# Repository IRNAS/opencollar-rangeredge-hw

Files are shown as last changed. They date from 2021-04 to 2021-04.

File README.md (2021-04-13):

# Opencollar RhinoEdge tracker hardware
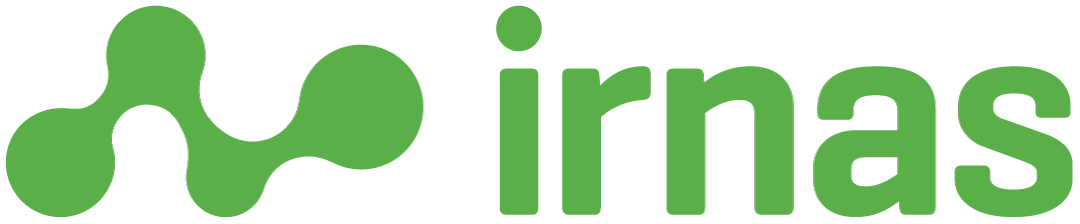
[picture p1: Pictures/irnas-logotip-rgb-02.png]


PCB specifications:
- 4 Layer PCB
- 1.6mm PCB thickness
- 0.127mm (5mil) trace to trace and trace to polygon clearance
- 0.137mm RF line thickness
- PCB dimensions 59.8mm x 95.8mm x 1.6mm

PCB view
<p align="center">
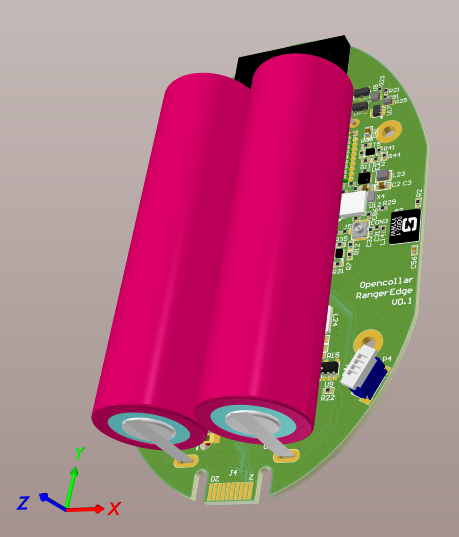
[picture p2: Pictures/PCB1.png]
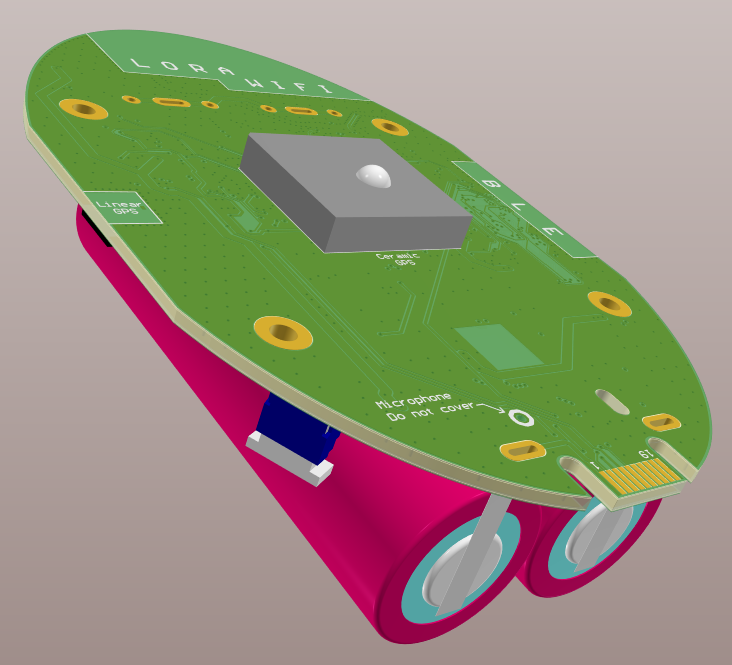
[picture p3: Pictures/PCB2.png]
					
</p>
 - Future changes:
	- 
  
Currently under development, for all information see the [schematic PDF file](https://github.com/IRNAS/opencollar-rangeredge-hw/tree/master/Documentation/RangerEdge_V0.1_SCHEMATICS).Produced board versions can be found in the [release section](https://github.com/IRNAS/opencollar-rangeredge-hw/releases) of the repository.

**Latest release: [v0.1](https://github.com/IRNAS/opencollar-rangeredge-hw/tree/master/Documentation)**

All comments and suggestions can be added to the [Issues](https://github.com/IRNAS/opencollar-rangeredge-hw/issues) section of the repo.

---

## Licensing

Pangolin tracker hardware with documentation is licensed under [CERN OHL v.1.2. license](https://www.ohwr.org/licenses/cern-ohl/license_versions/v1.2).

What this means is that you can use this hardware and documentation without paying a royalty and knowing that you'll be able to use your version forever. You are also free to make changes but if you share these changes then you have to do so on the same conditions that you enjoy.

IRNAS is name and mark of Institute IRNAS Rače. You may use these name and terms only to attribute the appropriate entity as required by the Open Licence referred to above. You may not use them in any other way and in particular you may not use them to imply endorsement or authorization of any hardware that you design, make or sell.
*

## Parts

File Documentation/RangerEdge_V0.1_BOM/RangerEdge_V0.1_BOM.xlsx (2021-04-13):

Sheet: Part List Report
 | Component list |  |  | RangerEdge
 | Source Data From: | RangerEdge.PrjPCB |  |  | Contact:
 | Project: | RangerEdge.PrjPCB
 | Variant: | None |  |  |  |  |  |  | IRNAS
 | Report Date: | 13. 04. 2021 | 08:22 |  |  |  |  |  | www.irnas.eu
 | Print Date: | 2021-04-13 | 8:22:18
# | Manufacturer Part Number | Manufacturer | Description | Footprint | Designator | Quantity | Supplier 1 | Supplier Part Number 1 | Supplier Order Qty 1 | Supplier Stock 1 | Supplier Unit Price 1 | Supplier Subtotal 1 | Supplier Currency 1
1 | LFXTAL009678 | IQD | Crystal, 32.768 kHz, SMD, 2mm x 1.2mm, 9 pF, 10 ppm, 9HT11 Series | 9HT11 | X4 | 1 | Farnell | 2819312
2 |  |  | BATERRY HOLDER 18650 | BATTERY 18650 - THT TAB | P2, P3 | 2
3 |  |  | Pin Header, Top Entry, Wire-to-Board, 1 mm, 1 Rows, 3 Contacts, Surface Mount, SR Series | BM02B-SRSS | P1 | 1 | Farnell | 1679127
4 |  |  | Pin Header, Top Entry, Wire-to-Board, 1 mm, 1 Rows, 4 Contacts, Surface Mount, SR Series | BM04B-SRSS | P4, P5 | 2 | Farnell | 1679129
5 | 04025A150JAT2A | Kyocera AVX | AVX 04025A150JAT2A Multilayer Ceramic Capacitor, 15 pF, 5%, C0G / NP0, 50 V, 0402 [1005 Metric] | CAP0402 | C56 | 1 | Farnell | 2367620
6 |  |  | CAP CER 27PF 50V C0G/NP0 0402 | CAP0402, rlc_402_smd_small | C39, C42, C43, C44, C45, C47, C48, C57, C58, C59 | 10 | Digi-Key | 490-11384-1-ND
7 | MC0402X104J160CT, CC0402JRX7R7BB104 | Multicomp, Yaego | MULTICOMP MC0402X104J160CT SMD Multilayer Ceramic Capacitor, 0402 [1005 Metric], 0.1 F, 16 V, 5%, X5R, MC Series New, CAP 100nF 16V X5R 0402, 0.1 F, 16 V, 5%, X5R, MC Series | CAP0402, rlc_402_smd_small | C1, C34, C49, C50, C52, C75, C77, C81, C84, C86, C88, C90 | 12 | Farnell | 2627419, 3369125
8 | CL10A106KP8NNNC, GRM188R60G226MEA0D | Samsung | Cap Ceramic 10uF 10V X5R 10% SMD 0603 85C Paper T/R, 22 µF, 4 V, 0603 [1608 Metric], ± 20%, X5R, GRM Series, CAP 10UF 10V X5R 0603 | CAP0603, rlc_603_smd_small | C2, C3, C51, C60, C61, C71, C74, C83 | 8 | Farnell, Digi-Key | 2456110, 1907502, 1276-1192-1-ND
9 | CGA4J1X5R1C106K125AC | TDK | 10UF, 16V, 0805 | CAP0805 | C72, C73 | 2 | Farnell | 2611943
10 | MM8130-2600 | Murata | Coaxial Connector with Switch | COAXIAL-SWF | J1, J2, J3, J5, J6, J7, J8 | 7
11 | ABS06-107-32.768KHZ-T | Abracon | 32.768KHz 4pF Max. ESR 81 Kohms | CRY2X1.2 | X1 | 1 | Farnell | 2467860
12 | ABS06-107-32.768KHZ-T | Abracon | TCXO Oscillators 32MHz 1ppm 1.7V to 3.465V | CRY2.5X2 | X2 | 1 | Mouser | 520-TXO25CSMV320BMTR
13 | NJG1801K75 | NJR | RF Switch ICs SPDT GaAs MMIC 6.0GHz 3.0V 31dBm | DFN-6-JRC | U4 | 1 | Mouser | 513-NJG1801K75
14 | NJG1804K64 | NJRC | SP3T SWITCH GAAS MMIC | DFN-8 | U2, U14 | 2 | Digi-Key | 190-NJG1804K64-TE1CT-ND
15 |  |  | TVS Diode, Unidirectional, 30 V, 48.4 V, DO-214AC (SMA), 2 Pins | DO-214AC (SMA) | D2 | 1 | Farnell | 1827605
16 | BGA725L6E6327FTSA1 | INFINEON | RF Amplifier IC, 20 dB Gain / 0.65 dB Noise, 1.55 GHz to 1.615 GHz | EPFFP6-X2 | U3, U5 | 2 | Farnell | 2480589
17 |  |  | Resettable Fuse, PPTC, 1210 (3225 Metric), MF-USHT Series, 30 VDC, 500 mA, 2.5 A, 0.1 s | FUSE 2920 | F1 | 1 | Farnell | 2776823
18 | SRN2009T-2R2M | Bourns | Power Inductor (SMD), 2.2 µH, 900 mA, Semishielded, 900 mA, SRN2009T Series, 2mm x 1.6mm x 0.95mm | IND2.3X1.7 | L22, L23 | 2 | Farnell | 2808272
19 |  |  | +FIXED IND 4.7NH 750MA 70MOHM | IND0402 | L17 | 1 | Farnell | 2285651
20 |  |  | FIXED IND 4.7NH 750MA 70MOHM | IND0402 | L18 | 1 | Digi-Key | 490-1139-1-ND
21 |  |  | ISP Smart Bluetooth Module | ISP1807-LR | U20 | 1 | Digi-Key | 1786-1019-1-ND
22 | KPTL-3216SURCK-01 | KINGBRIGHT | LED, Low Power, Red, SMD - Reverse Mount, 1206 (3216 Metric), 20 mA, 1.95 V, 630 nm | LED1206 - Reverse | D3 | 1 | Farnell | 2217903
23 | MPU-9250 | TDK InvenSense | MEMS Accelerometer, Digital, X, Y, Z, ± 2g, ± 4g, ± 8g, ± 16g, 1.62 V, 3.6 V | LGA-12 | U11 | 1 | Farnell | 2849615
24 | 1N4148W-7-F. | DIODES INC. | Bridge Rectifier Diode, Single Phase, 100 V, 500 mA, SOIC, 1 V, 4 Pins | MB1S | D4 | 1 | Farnell | 1467483
25 | SR42I010-R | Antenova | Antennas Passive GPS/GLONASS Patch Antenna | MPA-184 | A1 | 1 | Digi-Key | 931-1408-ND
26 | LM2596DSADJG | ON SEMICONDUCTOR | Li-Ion Battery, Li-Pol Voltage & Current Protector, Single Cell, 1.5 V to 8 V supply, | PWSON-6 | U8 | 1 | Farnell | 3123826
27 |  |  | LR1110 - Low Power Integrated UHF Transceiver with LoRa Modem | qfn32l_5x5mm | U1 | 1
28 | L76-M33 | Quectel | GPS Modules GNSS | Quectel-L76 | U25 | 1 | Mouser | 277-L76-M33
29 | MCWR04X1002FTL | Multicomp | 52.3 kohm, 50 V, 0402 [1005 Metric], 62.5 mW, 1%, MCWR Series, 10 kohm, 50 V, 0402 [1005 Metric], 62.5 mW, 1%, MCWR Series, 10 kohm, 50 V, 0402, 62.5 mW, 1%, | RES0402 | R15, R17, R19 | 3 | Farnell | 2073114, 2447096
30 | CRCW0402165KFKED | Vishay | RES SMD 165K OHM 1% 1/16W 0402 | RES0402 | R16 | 1 | Farnell | 2072686
31 | MCMR06X4701FTL | MULTICOMP | 4.7 kohm, MCWR Series, 50 V | RES0402, rlc_402_smd_small | R7, R9, R12, R13, R32, R34 | 6 | Farnell | 2447187
32 | MCWR04X1003FTL | Multicomp | MULTICOMP MCWR04X1003FTL RES, THICK FILM, 100KOHM, 1%, 0.0625W, 100KOHM, 1%, 0.0625W | RES0402, rlc_402_smd_small | R4, R29, R37, R38, R41, R42, R48, R49 | 8 | Farnell | 2447094
33 | MCMR04X000PTL | Multicomp | RESISTOR, 0402, 0R, ANTI SULFURATION | RES0402, rlc_402_smd_small | R2, R22, R31, R35, R40, R44, R46, R47 | 8 | Farnell | 2072513
34 | GRT155R71H471KE01D | Murata |  | rlc_402_smd_small | C35 | 1 | Farnell | 2672128
35 | MCMR04X3300FTL | Multicomp | 330 ohm, 62.5 mW, 1%, 50 V, 0402 [1005 Metric] | rlc_402_smd_small | R21 | 1 | Farnell | 2692084
36 |  |  | CAP CER 0.5PF 50V C0G/NP0 0402 | rlc_402_smd_small | C24, C26 | 2 | Digi-Key | 490-6264-1-ND
37 |  |  | CAP CER 0.7PF 50V C0G/NP0 0402 | rlc_402_smd_small | C30 | 1 | Digi-Key | 490-6267-1-ND
38 |  |  | CAP CER 1nF 50V C0G/NP0 0402 | rlc_402_smd_small | C41, C46 | 2 | Farnell | 2470415
39 |  |  | CAP CER 1.3PF 50V C0G/NP0 0402 | rlc_402_smd_small | C27 | 1 | Digi-Key | 490-8190-1-ND
40 | [NoParam], GRM1555C1H1R5BA01D | [NoParam], Murata | CAP CER 1.5PF 50V C0G/NP0 0402, CAP 1.5PF 50V C0G/NP0 0402 | rlc_402_smd_small | C17, C19, C23, C32 | 4 | Digi-Key | 490-6212-1-ND
41 |  |  | CAP CER 1.6PF 50V C0G/NP0 0402 | rlc_402_smd_small | C28 | 1 | Digi-Key | 490-6214-1-ND
42 |  |  | CAP CER 1.8PF 50V C0G/NP0 0402 | rlc_402_smd_small | C12 | 1 | Digi-Key | 490-6215-1-ND
43 |  |  | CAP CER 2.2nF 50V C0G/NP0 0402 | rlc_402_smd_small | C5 | 1 | Digi-Key | 490-1305-1-ND
44 |  |  | CAP CER 3.0PF 50V C0G/NP0 0402 | rlc_402_smd_small | C13 | 1 | Digi-Key | 490-7756-1-ND
45 |  |  | CAP CER 6.8PF 50V C0G/NP0 0402 | rlc_402_smd_small | C9, C14 | 2 | Digi-Key | 490-5949-1-ND
46 |  |  | CAP CER 12PF 50V C0G/NP0 0402 | rlc_402_smd_small | C25 | 1 | Digi-Key | 490-5924-1-ND
47 |  |  | CAP CER 33PF 50V C0G/NP0 0402 | rlc_402_smd_small | C29 | 1 | Digi-Key | 490-5936-1-ND
48 | C1005C0G1H470G050BA | TDK | CAP CER 47PF 50V 2% C0G 0402 | rlc_402_smd_small | C91 | 1 | Farnell | 2525003
49 |  |  | CAP CER 47PF 50V C0G/NP0 0402 | rlc_402_smd_small | C6, C7, C10, C15, C21 | 5 | Digi-Key | 490-5942-1-ND
50 | GRM155R71C103KA01D | Murata | CAP CER 10000PF 16V X7R 0402 | rlc_402_smd_small | C87 | 1 | Farnell | 2407354
51 |  |  | CAP CER ???F ??V 0402 | rlc_402_smd_small | C11, C16, C20, C53 | 4 | Digi-Key | 490-8190-1-ND
52 | MC0402N120J500CT | MULTICOMP | Ceramic Capacitor, 12 pF, 50 V, 0402 | rlc_402_smd_small | C36, C37 | 2 | Farnell | 1758943
53 |  |  | Ferrite Bead, 0402 [1005 Metric], 1 kohm, 200 mA, BLM15AG_SN Series, 1 ohm, ± 25% | rlc_402_smd_small | L2 | 1 | Farnell | 1515759
54 |  |  | FIXED IND 2.7NH 850MA 50 MOHM | rlc_402_smd_small | L7 | 1 | Digi-Key | 490-6800-1-ND
55 |  |  | FIXED IND 3.6NH 900MA 40 MOHM | rlc_402_smd_small | L15, L20 | 2 | Digi-Key | 490-6811-1-ND
56 |  |  | FIXED IND 6.8NH 700MA 90 MOHM | rlc_402_smd_small | L8 | 1 | Digi-Key | 490-1142-1-ND
57 |  |  | FIXED IND 7.5NH 570MA 130 MOHM | rlc_402_smd_small | L16, L21 | 2 | Digi-Key | 490-6846-2-ND
58 |  |  | FIXED IND 8.2NH 540MA 140 MOHM | rlc_402_smd_small | L6 | 1 | Digi-Key | 490-1144-1-ND
59 |  |  | FIXED IND 9.5NH 540MA 140 MOHM | rlc_402_smd_small | L11, L13 | 2 | Digi-Key | 490-8445-1-ND
60 |  |  | FIXED IND 22NH 310MA 300 MOHM | rlc_402_smd_small | L9 | 1 | Digi-Key | 490-6788-1-ND
61 |  |  | FIXED IND 33NH 260MA 630 MOHM | rlc_402_smd_small | L12 | 1 | Digi-Key | 490-1152-1-ND
62 |  |  | FIXED IND 47NH 210MA 1.08 OHM | rlc_402_smd_small | L3, L4, L10 | 3 | Digi-Key | 490-1154-1-ND
63 | LQG15WH18NJ02D | MURATA | IND 18NH 260MA 0.8 OHM 0402 | rlc_402_smd_small | L14 | 1 | Farnell | 3263541
64 | GRM1555C1H100FA01D | Murata | Multilayer Ceramic Capacitors MLCC - SMD/SMT 0402 10pF 50volts C0G 1% | rlc_402_smd_small | C33 | 1 | Farnell | 2611888
65 | MCMR04X000PTL | Multicomp | RESISTOR, 0402, 768k, ANTI SULFURATION | rlc_402_smd_small | R6, R11 | 2 | Farnell | 2670555
66 |  | Multicomp | SMD Chip Resistor, 0402 [1005 Metric], 220 ohm, CRCW e3 Series, 50 V, Thick Film, 63 mW | rlc_402_smd_small | R1, R36 | 2 | Farnell | 2140704
67 |  | Multicomp | SMD Chip Resistor, 0402 [1005 Metric], 390 ohm, MCWR Series, 50 V, Thick Film, 62.5 mW | rlc_402_smd_small | R39 | 1 | Farnell | 2447165
68 | CL05A474KP5NNNC | SAMSUNG ELECTRO-MECHANICS | SMD Multilayer Ceramic Capacitor, 0.47 µF, 10 V, 0402 [1005 Metric], ± 10%, X5R, CL Series | rlc_402_smd_small | C4 | 1 | Farnell | 3013336
69 |  |  | CAP CER 1PF 50V C0G/NP0 0402 | rlc_402_smd_small, CAP0402 | C22, C40 | 2 | Digi-Key | 490-6206-1-ND
70 | GRM155R61A105ME15D | Murata | CAP CER 1UF 10V 20% X5R 0402 | rlc_402_smd_small, CAP0402 | C38, C55, C76, C80, C82, C85, C93, C94 | 8 | Farnell | 2426953, 1740588
71 | [NoParam], GRM1555C1H1R2BA01D | [NoParam], Murata | CAP CER 1.2PF 50V C0G/NP0 0402, CAP 1.2PF 50V C0G/NP0 0402 | rlc_402_smd_small, CAP0402 | C8, C18, C31, C54 | 4 | Digi-Key | 490-6209-1-ND
72 |  |  | FIXED IND 3.3NH 2A 30 MOHM SMD | rlc_402_smd_small, IND0402 | L5, L19 | 2 | Digi-Key | 490-7642-1-ND
73 | MCWR04X2001FTL | Multicomp | 2.2 kohm, 62.5 mW, 1%, 50 V, 2 kohm, 62.5 mW, 1%, 50 V | rlc_402_smd_small, RES0402 | R23, R24 | 2 | Farnell | 2447148, 2447147
74 | MC0063W060311M | MULTICOMP | MCMR04X1004FTL RES, 1M, 1%, 0.0625W, 0402, THICK FILM | rlc_402_smd_small, RES0402 | R5, R10, R14, R20, R26, R28 | 6 | Farnell | 9330410
75 | MCMR04X1000FTL | Multicomp | MULTICOMP MCMR04X1000FTL SMD Chip Resistor, Ceramic, MCMR Series, 100 ohm, 50 V, 0402 [1005 Metric], 62.5 mW, 1%, 100 ohm, 50 V, 0402 [1005 Metric], 62.5 mW, 1% | rlc_402_smd_small, RES0402 | R3, R8, R18, R27, R45 | 5 | Farnell | 2072515
76 | CR0603-J/-000ELF | BOURNS | BOURNS - CR0603-J/-000ELF - RES, THICK FILM, 0R, 5%, 0.1W, 0603 | rlc_603_smd_small | R25 | 1 | Farnell | 2008343
77 | MLZ2012M150WT000 | TDK | Fixed Inductors 15 UH 20% | rlc_805_smd_small | L1 | 1 | Mouser | 810-MLZ2012M150WT000
78 | TPS22919DCKR | TI | Power Switch/Driver 1:1 N-Channel 1.5A SC-70-6 | SC70-6 | U13, U15, U17, U18 | 4 | Digi-Key | 296-TPS22919DCKRCT-ND
79 | MAX-M8Q-0 | u-blox | ZOE-M8 RF Receiver BeiDou, Galileo, GLONASS, GNSS, GPS -160dBm | S-LGA51 | U12 | 1 | Digi-Key | 672-1063-1-ND
80 |  |  | TVS DIODE 24V 7V SLP0603P2X3F | SLP0603P2X3F | D6 | 1
81 | 1N4148W-7-F. | DIODES INC. | TVS Diode, ESD9R Series, Unidirectional, 3.3 V, 7.8 V | SOD-923 | D1 | 1 | Farnell | 1776392
82 | EN25QH32B-104HIP2C | ESMT | 32 Megabit Serial Flash Memory with 4Kbyte Uniform Sector | SOIC-8 REFLOW | U19 | 1
83 | MPU-9250 | TDK InvenSense | Board Mount Hall Effect/Magnetic Sensors LP HALL 32FBDBZR | SOT23-3AL | U10 | 1 | Mouser | 595-DRV5032FBDBZR
84 | DMG2302UK-7 |  | MOSFET Transistor, N Channel, 2.8 A, 20 V, 0.061 ohm, 4.5 V, 600 mV | SOT23-3AL | T2 | 1 | Farnell | 3127315
85 | SI2374DS-T1-GE3 |  | MOSFET Transistor, N Channel, 5.9 A, 20 V, 0.025 ohm, 4.5 V, 1 V | SOT23-3AL | T3, T4 | 2 | Farnell | 2646371
86 | BD70522GUL | ROHM | Battery Charger for 1 Cell of Li-Ion, Li-Pol battery, 6V input, 4.2V / 500mA charge | SOT23-5 | U9 | 1 | Farnell | 1627187
87 | NTZD3154NT1G |  | Dual MOSFET, Dual N Channel, 540 mA, 20 V, 0.4 ohm, 4.5 V, 1 V | SOT-563 | T1, T5 | 2 | Farnell | 2533209
88 | SR4L049-L | Antenova | Antennas Inversa Left LTE Antenna | SR4L049-L | A3 | 1 | Mouser | 237-SR4L049-L
89 | DR125-330-R | COILTRONICS | Power Inductor (SMD), 22 µH, 1.1 A, Semishielded, 1.1 A, SRN5020TA Series, 5mm x 5mm x 1.8mm | SRN5020TA | L24 | 1 | Mouser | 652-SRN5020TA-220M
90 | SZP-C-0G02 | SYNZEN | GNSS: GPS, GLONASS, GALILEO, Beidou: 1.559 – 1.610 GHz | SZP-C-0G02-1 | A2 | 1
91 | BD70522GUL | ROHM | DC-DC Synchronous Buck Regulator, Adjustable, 4.4V to 30V In, 2V to 24V/1A Out, 500kHz | TDFN-8 | U7 | 1 | Farnell | 2857600
92 |  |  | TEST POINT ROUND SMD | TestPoint:1.2x1.2mm | TP3, TP4, TP5 | 3
93 | BD70522GUL | ROHM | Switching Voltage Regulators Tiny 300nA nanoPower Buck converters in uDFN and WLP pacakges | uDFN-6 | U6, U22 | 2 | Mouser | 700-MAX38640AELT+T
94 | U.FL-R-SMT-1(10) | Hirose | RF / Coaxial Connector, U.FL Coaxial, Straight Jack, Surface Mount Vertical, 50 ohm, Brass | ufl connector smd | CON1, CON2, CON3, CON4 | 4 | Farnell | 1688077
95 | VM1010 | Vesper | MICROPHONE MEMS DIGITAL PDM OMNI | VM1010 | U16 | 1
 |  |  |  |  |  | 209 |  |  | 0 |  |  | 0
Approved |  |  |  | Notes
 |  |  |  | pcs: |  | 20 |  | Total |  | 0 |  | <none>
 |  |  |  |  |  |  |  | Price for 1pcs |  | 0.00 |  | <none>

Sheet: Project Information
Project Full Path | D:\Synology Drive\IRNAS-Projects\SmartParks\SmartParks - RangerTracker\RangerEdge.PrjPCB
Project Filename | RangerEdge.PrjPCB
Variant Name | None
Data-Source Filename | RangerEdge.PrjPCB
Data-Source Full Path | D:\Synology Drive\IRNAS-Projects\SmartParks\SmartParks - RangerTracker\RangerEdge.PrjPCB
Title | BOM for Project [RangerEdge.PrjPCB] (No PCB Document Selected)
Total Quantity | 209
Report Time | 08:22
Report Date | 13. 04. 2021
Report Date & Tine | 13. 04. 2021 08:22
Output Name | BOM
Output Type | BOM_PartType
Output Generator Name | BOM
Output Generator Description | Bill of Materials

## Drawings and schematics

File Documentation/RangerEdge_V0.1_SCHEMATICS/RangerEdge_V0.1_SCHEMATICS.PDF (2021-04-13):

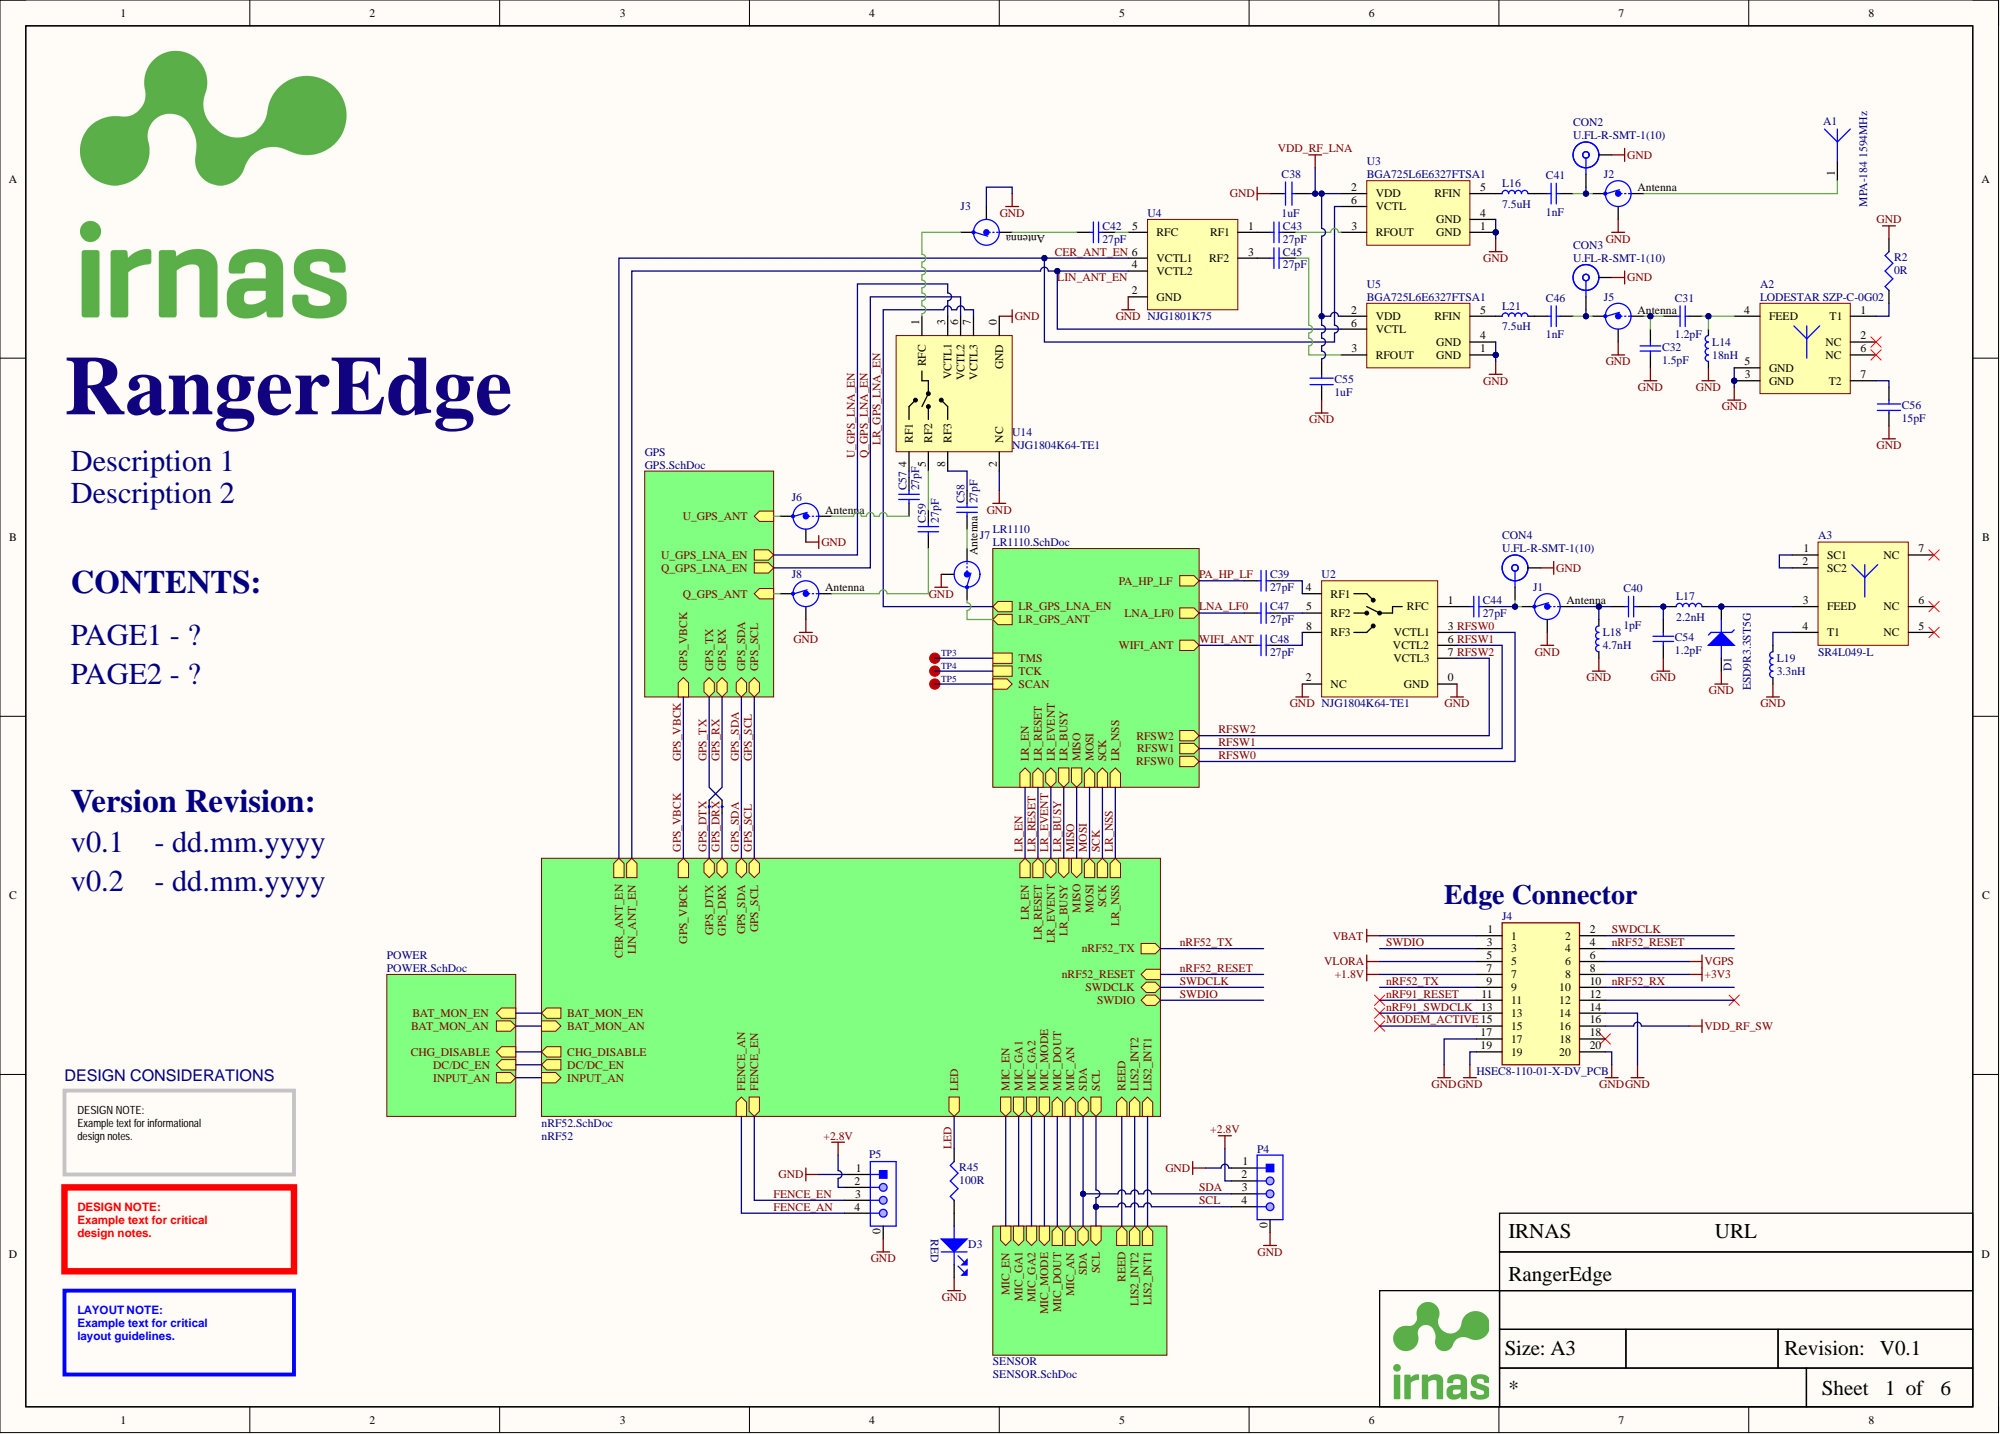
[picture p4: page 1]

VCTL2 4 | 27pF

GND 2

LR_GPS_LNA_EN LR_GPS_ANT SCAN | PA_HP_LF LNA_LF0 WIFI_ANT RFSW0 LR_NSS RFSW2 RFSW1

WIFI_ANT | C48 | | | VCTL2 | 6 VCTL1 3 RFSW1

27pF | VCTL3 | 7 RFSW2

RFSW2 | NC 2

DESIGN NOTE:
Example text for informational
design notes.

Example text for critical

LAYOUT NOTE:
layout guidelines.

Size: A3 | | Revision: V0.1

Sheet of

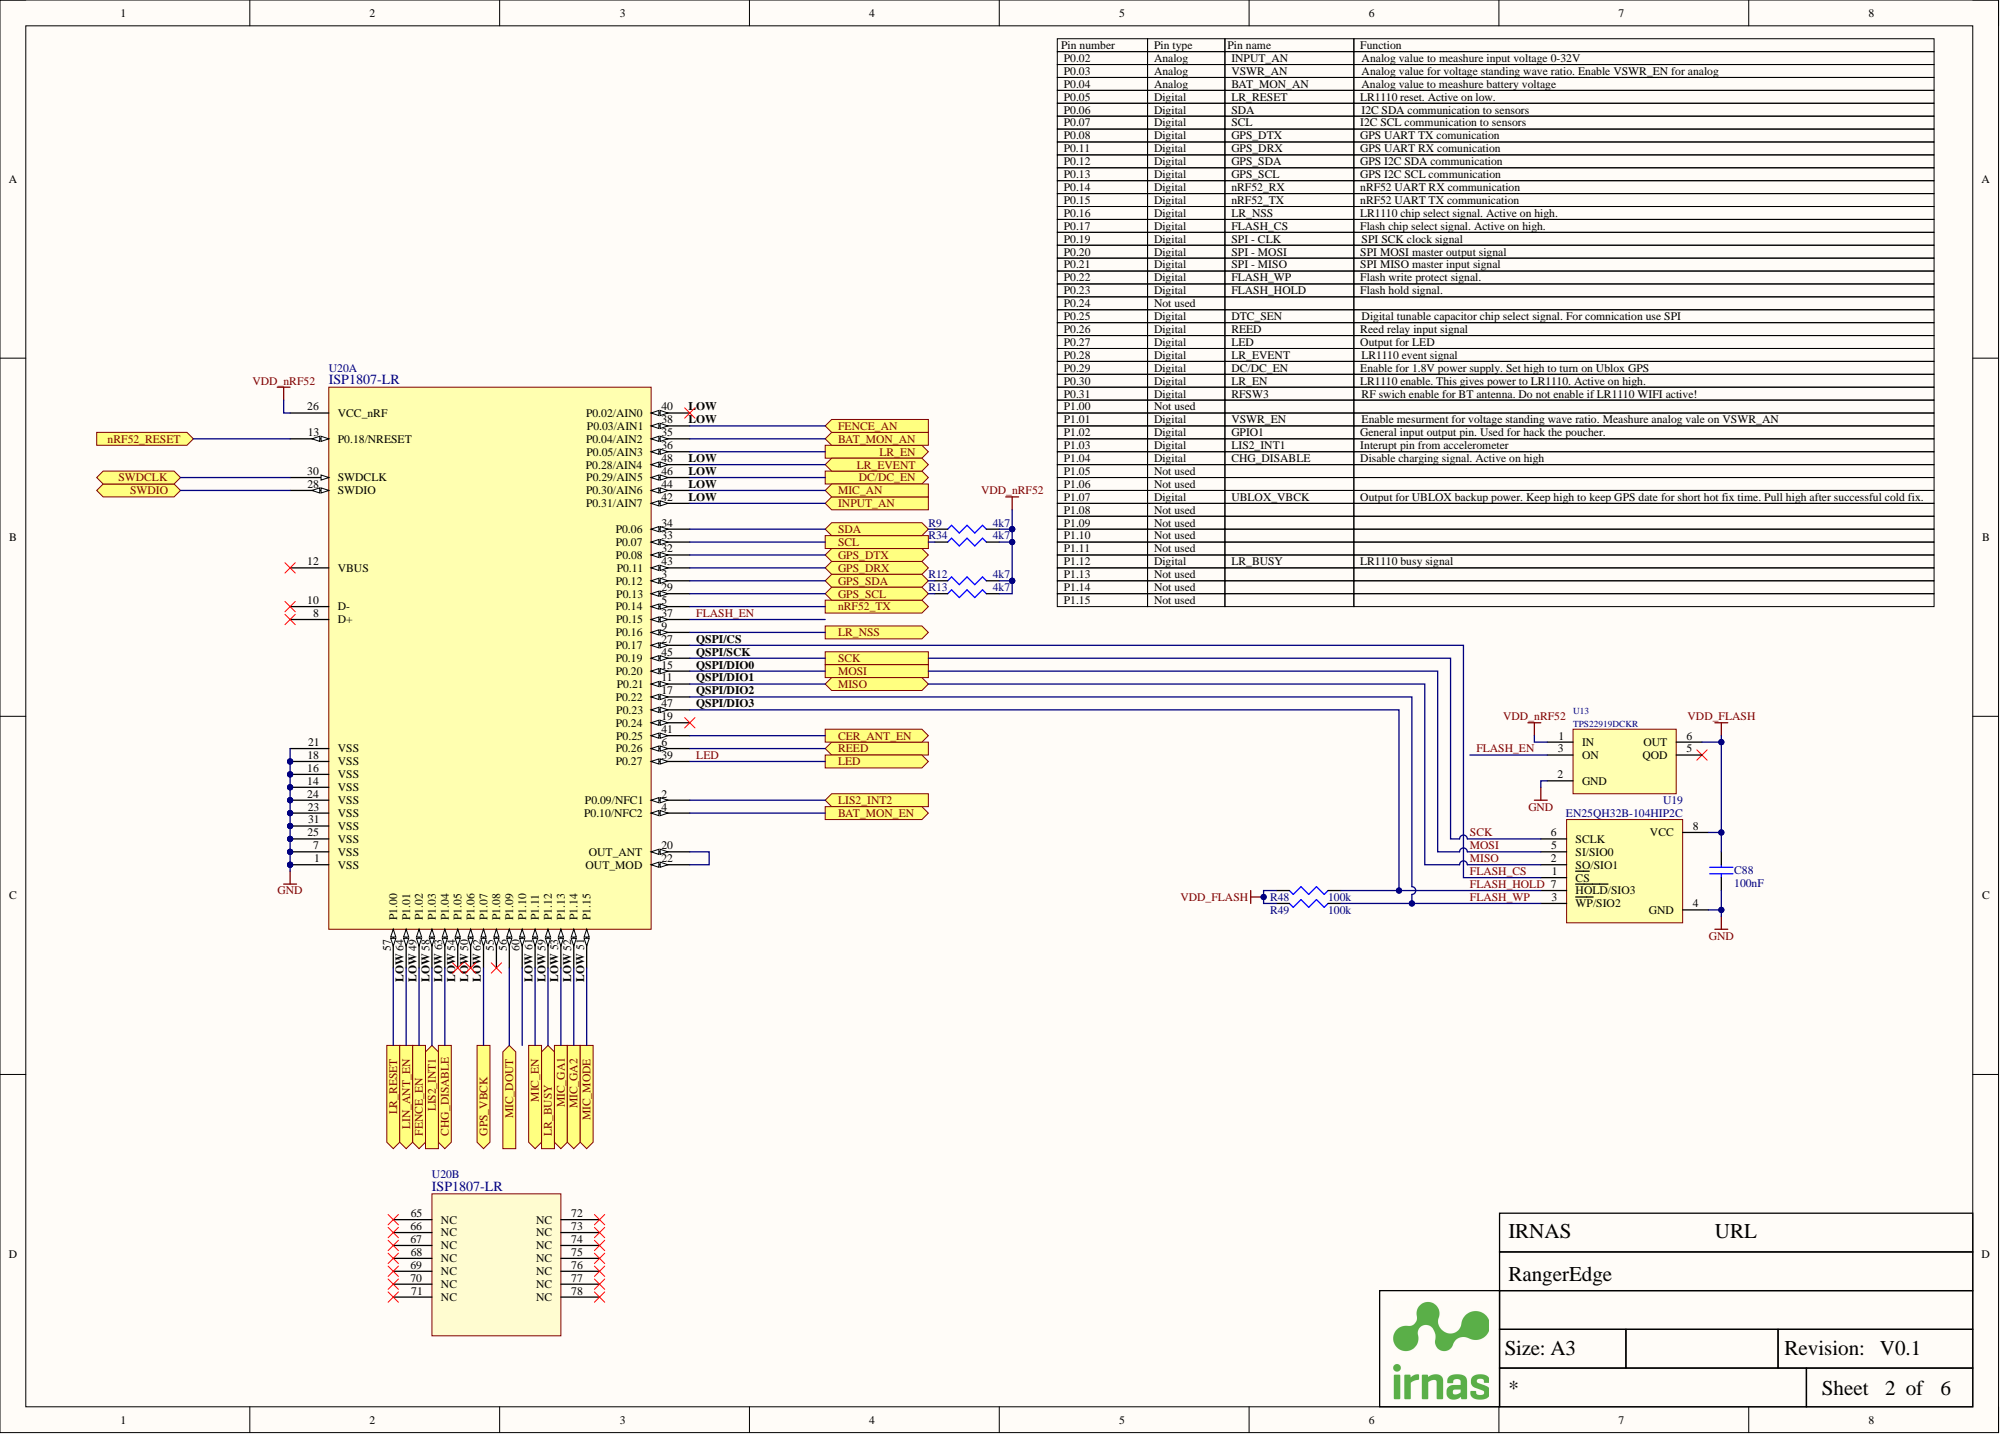
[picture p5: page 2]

Pin number | Pin type | Pin name | Function
P0.02 | Analog | INPUT_AN | Analog value to meashure input voltage 0-32V
P0.03 | Analog | VSWR_AN | Analog value for voltage standing wave ratio. Enable VSWR_EN for analog
P0.04 | Analog | BAT_MON_AN | Analog value to meashure battery voltage
P0.05 | Digital | | LR1 110 reset. Active on low .
P0.06 | Digital | SDA | I2C SDA communication to sensors

P0.07 | Digital | LR_RESET GPS_DTX GPS_DRX GPS_SDA GPS_SCL SCL | I2C SCL communication to sensors

P0.08 | Digital | | GPS UAR T TX comunication
P0.1 1 | Digital | | GPS UAR T RX comunication
P0.12 | Digital | | GPS I2C SDA communication
P0.13 | Digital
P0.14 | Digital | nRF52_RX | nRF52 UAR T RX communication

P0.15 | Digital | nRF52_TX | SPI MOSI master output signal GPS I2C SCL communication nRF52 UAR T TX communication

P0.16 | Digital | LR_NSS | LR1 110 chip select signal. Active on high.
P0.17 | Digital | FLASH_CS
P0.19 | Digital | SPI - CLK | SPI SCK clock signal
P0.20 | Digital | SPI - MOSI
P0.21 | Digital | SPI - MISO | SPI MISO master input signal
P0.22 | Digital | FLASH_WP | Flash write protect signal.

P0.23 | Digital | FLASH_HOLD | Flash chip select signal. Active on high. General input output pin. Used for hack the poucher Flash hold signal.

P0.24 | Not used
P0.25 | Digital | DTC_SEN | Digital tunable capacitor chip select signal. For comnication use SPI
P0.26 | Digital | REED | Reed relay input signal
P0.27 | Digital | LED | Output for LED
P0.28 | Digital | LR_EVENT | LR1 110 event signal
P0.29 | Digital | DC/DC_EN | Enable for 1.8V power supply. Set high to turn on Ublox GPS
P0.30 | Digital | LR_EN | LR1 110 enable. This gives power to LR1 110. Active on high.

RF swich enable for BT antenna. Do not enable if LR1

Enable mesurment for voltage standing wave ratio. Meashure analog vale on VSWR_AN

P1.02 | Digital | | .
P1.03 | Digital | LIS2_INT1 | Interupt pin from accelerometer

Disable charging signal. Active on high

P1.07 | Digital | UBLOX_VBCK | Output for UBLOX backup power. Keep high to keep GPS date for short hot fix time. Pull high after successful cold fix.
P1.08 | Not used
P1.09 | Not used
P1.10 | Not used
P1.1 1 | Not used
P1.12 | Digital | LR_BUSY | LR1 110 busy signal

QSPI/DIO0

QSPI/DIO3

VSS 18 | | LED
VSS 16 | 2

FLASH_CS
FLASH_HOLD | 7

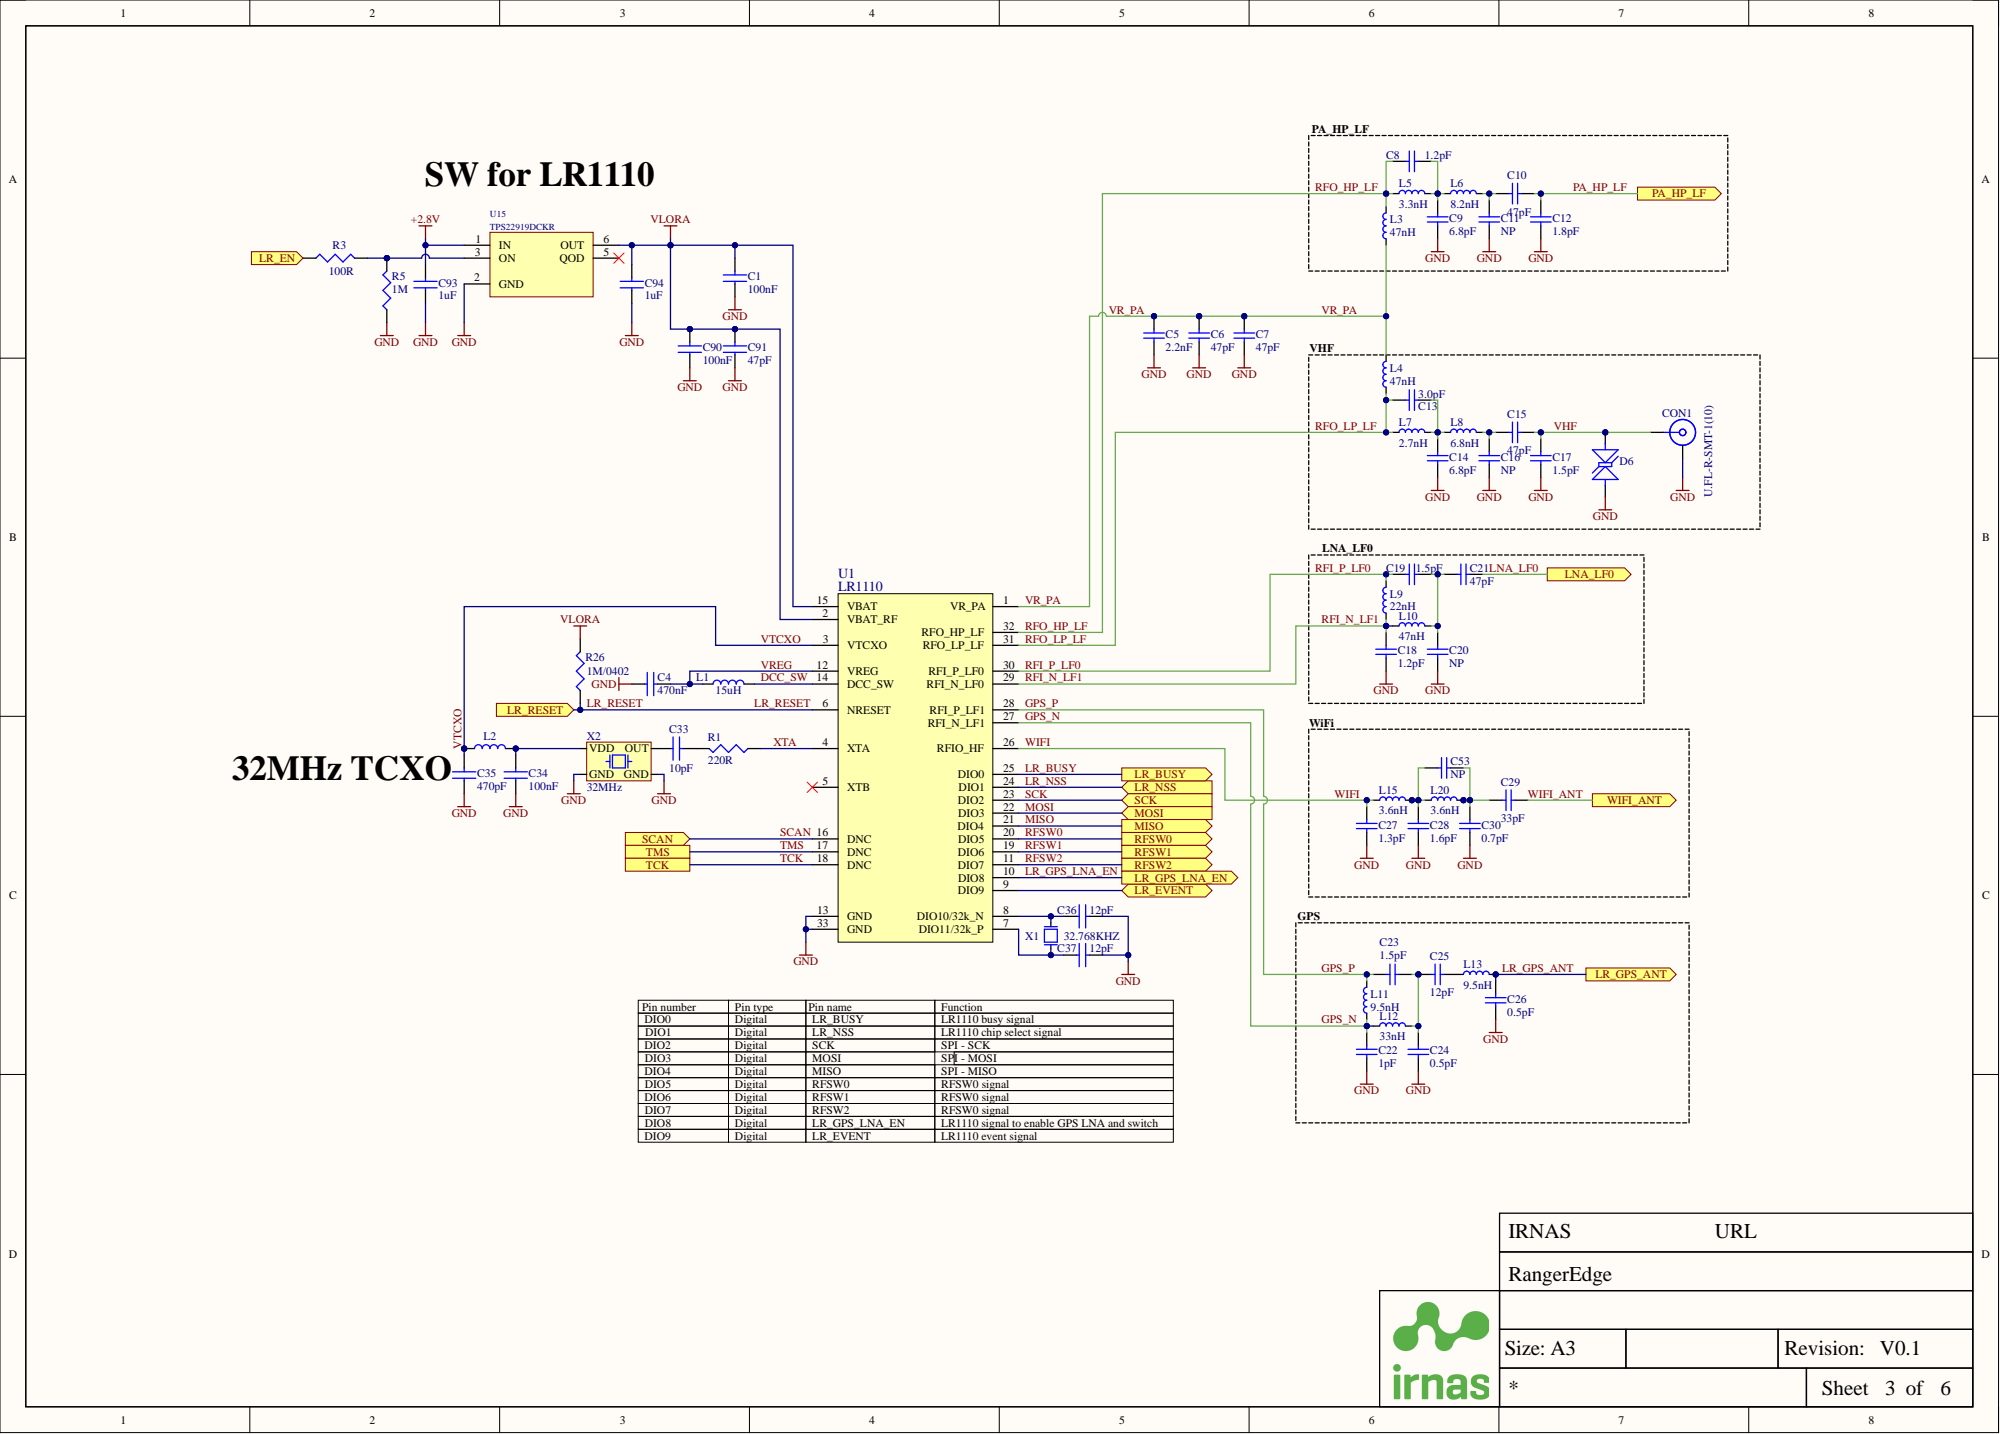
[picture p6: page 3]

LNA_LF0 RFI_P_LF0

VR_P A | RFI_N_LF1

Pin number | Pin type | Pin name | Function
DIO0 | Digital | LR_BUSY | LR1 110 busy signal
DIO1 | Digital | LR_NSS | LR1 110 chip select signal
DIO2 | Digital | SCK | SPI - SCK
DIO3 | Digital | MOSI | SPI - MOSI
DIO4 | Digital | MISO | SPI - MISO
DIO5 | Digital | RFSW0 | RFSW0 signal
DIO6 | Digital | RFSW1 | RFSW0 signal
DIO7 | Digital | RFSW2 | RFSW0 signal
DIO8 | Digital | LR_GPS_LNA_EN | LR1 110 signal to enable GPS LNA and switch
DIO9 | Digital | LR_EVENT | LR1 110 event signal

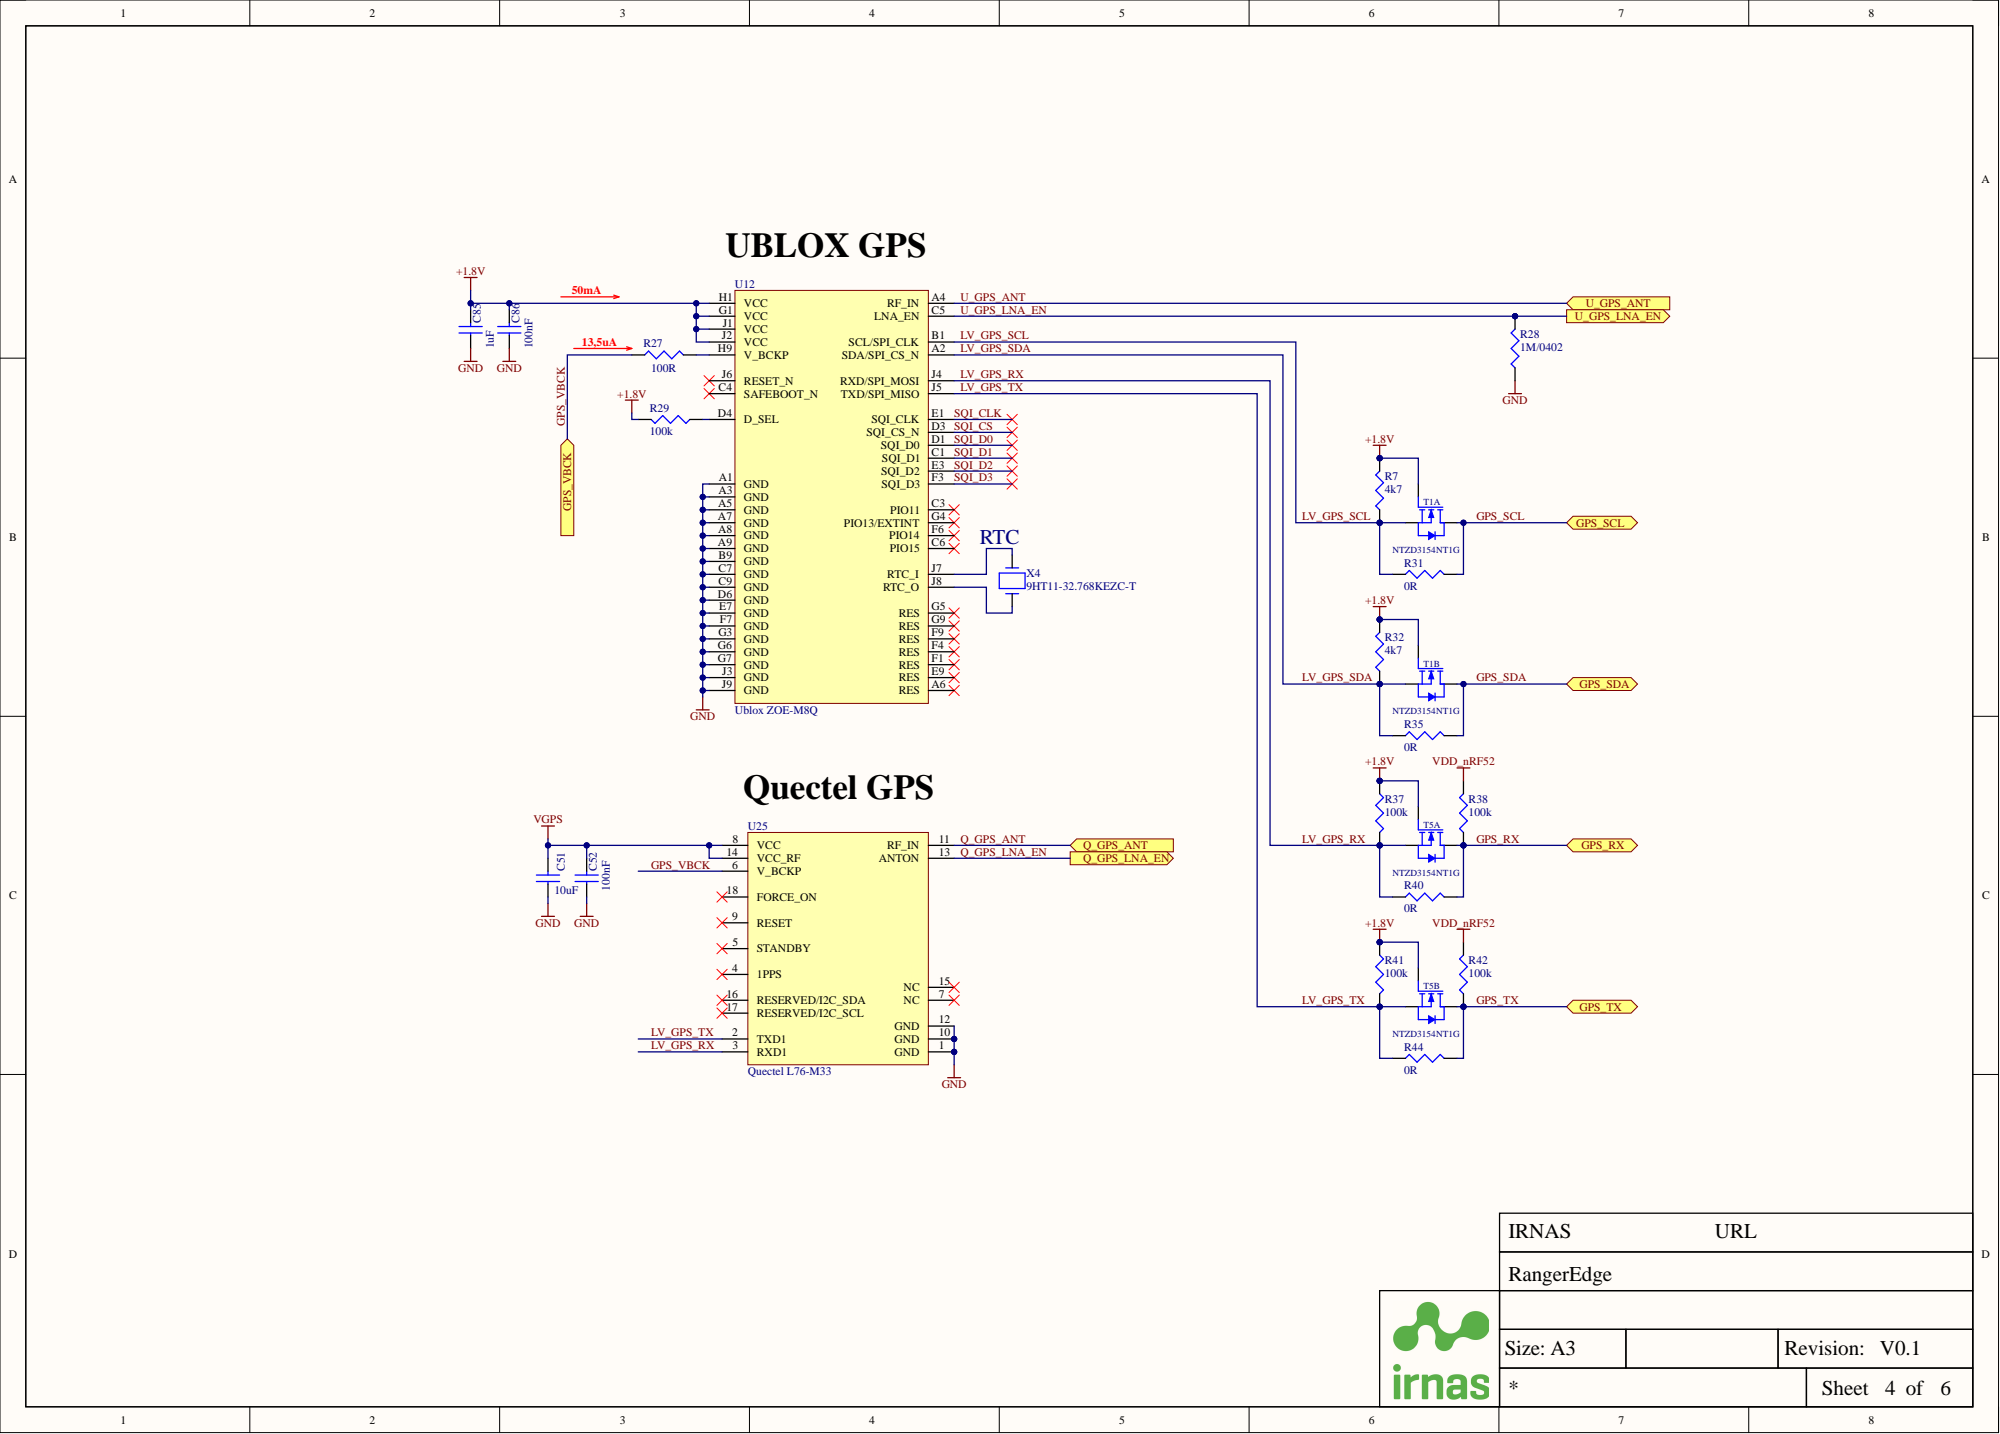
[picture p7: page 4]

LV_GPS_TX

SQI_CLK

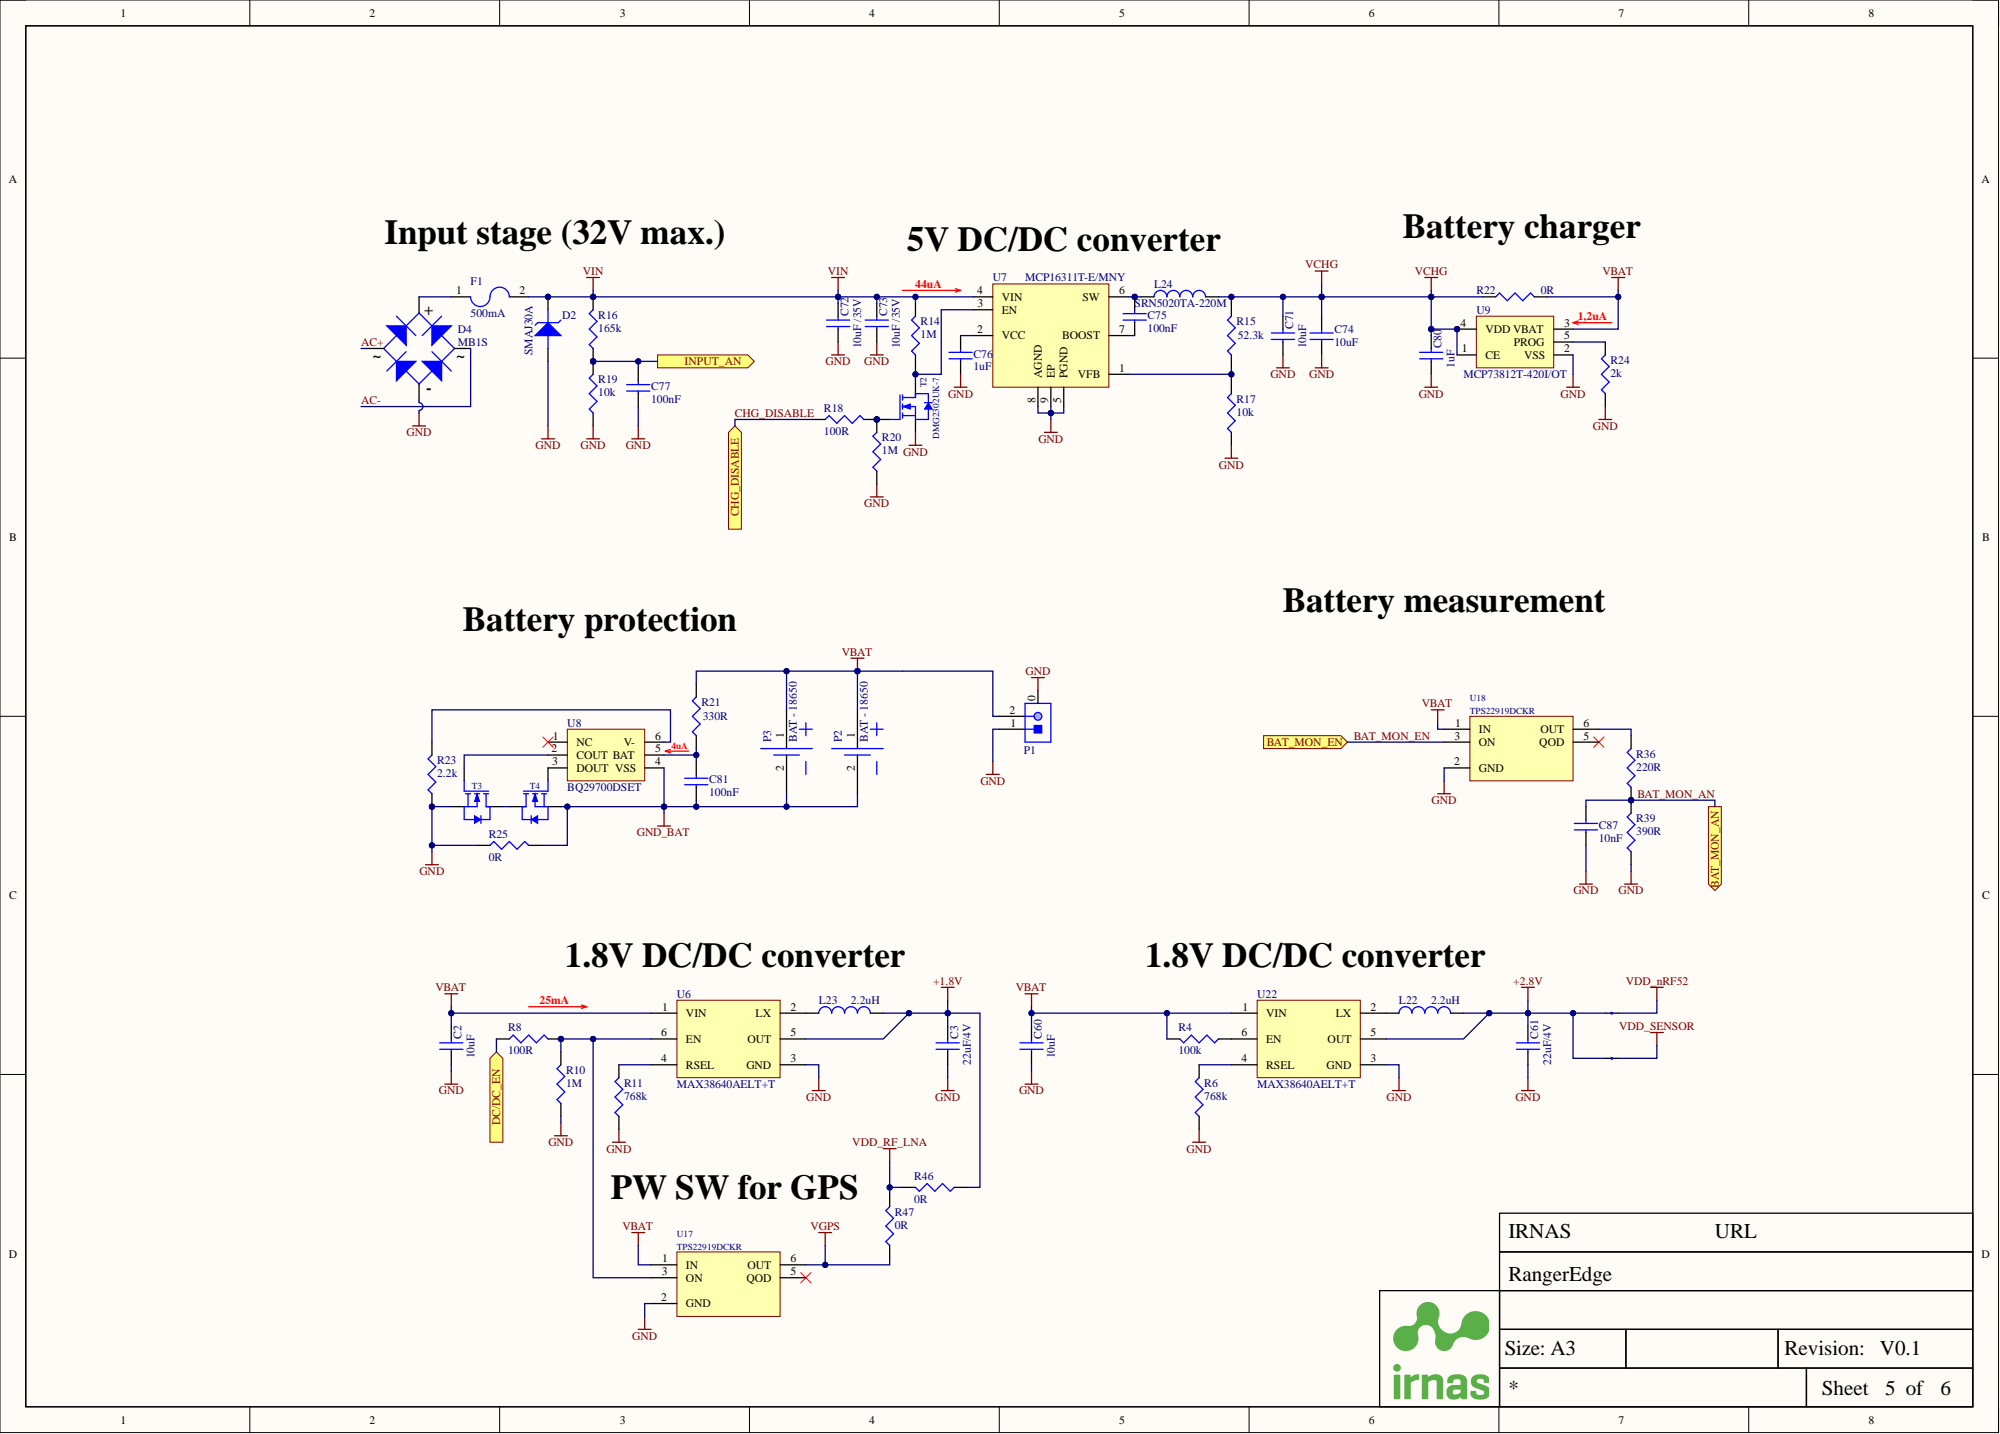
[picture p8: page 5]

DOUT 3 VSS COUT 2 | 4 BAT 5 V-6

GND
PW SW for GPS

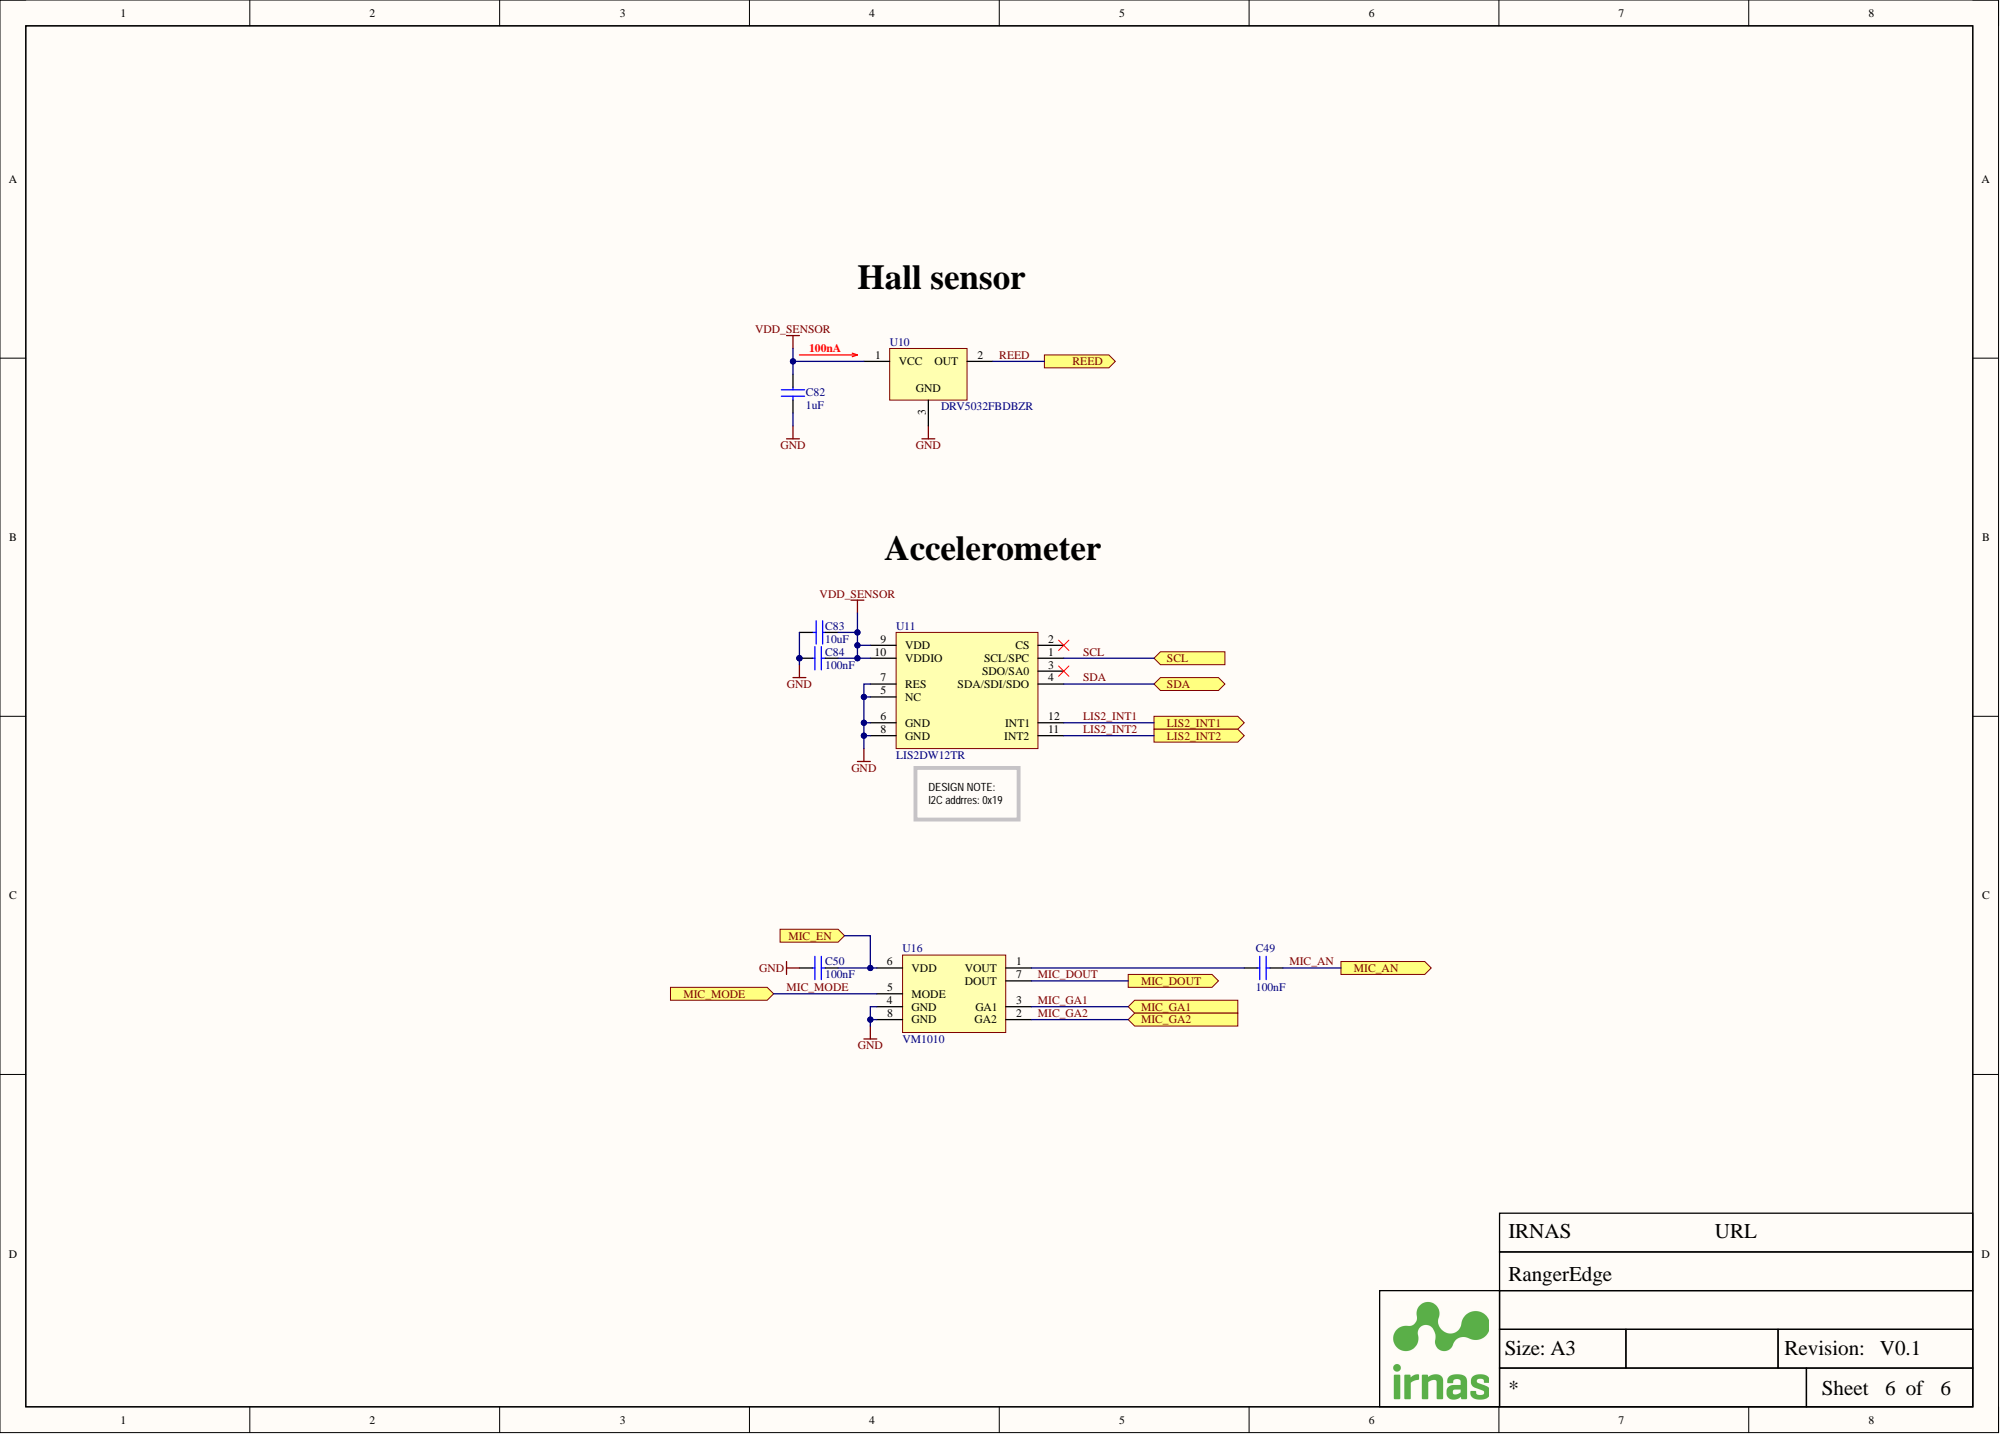
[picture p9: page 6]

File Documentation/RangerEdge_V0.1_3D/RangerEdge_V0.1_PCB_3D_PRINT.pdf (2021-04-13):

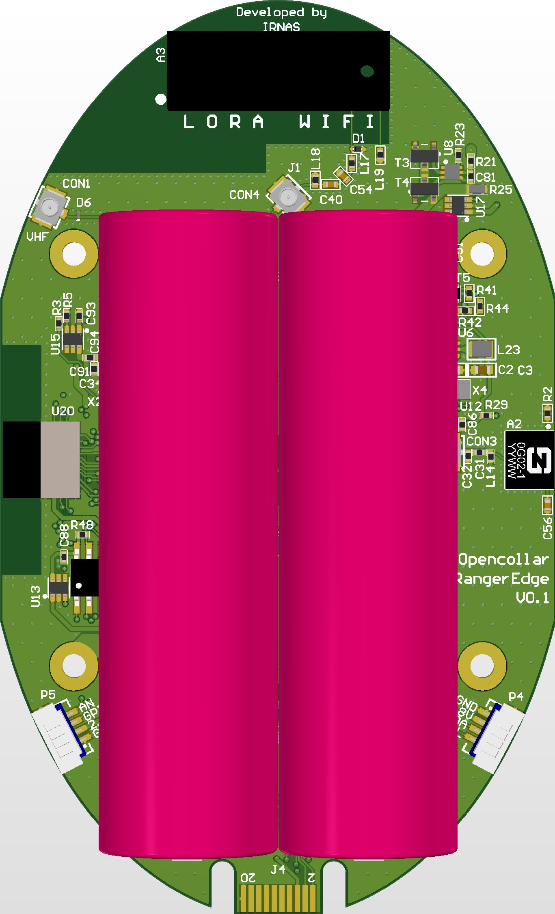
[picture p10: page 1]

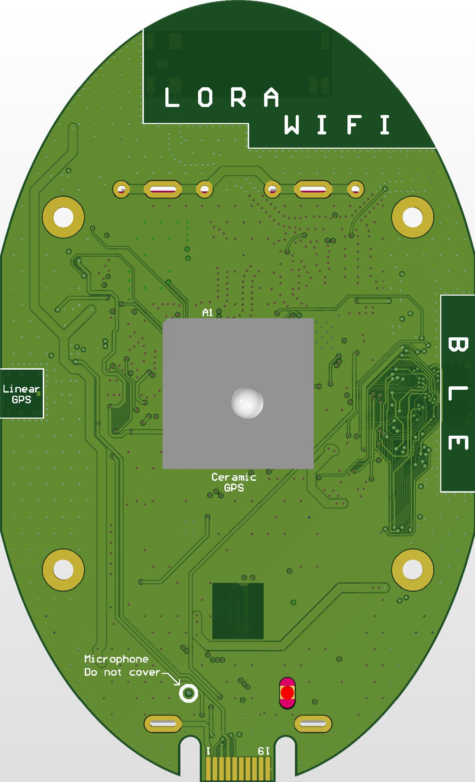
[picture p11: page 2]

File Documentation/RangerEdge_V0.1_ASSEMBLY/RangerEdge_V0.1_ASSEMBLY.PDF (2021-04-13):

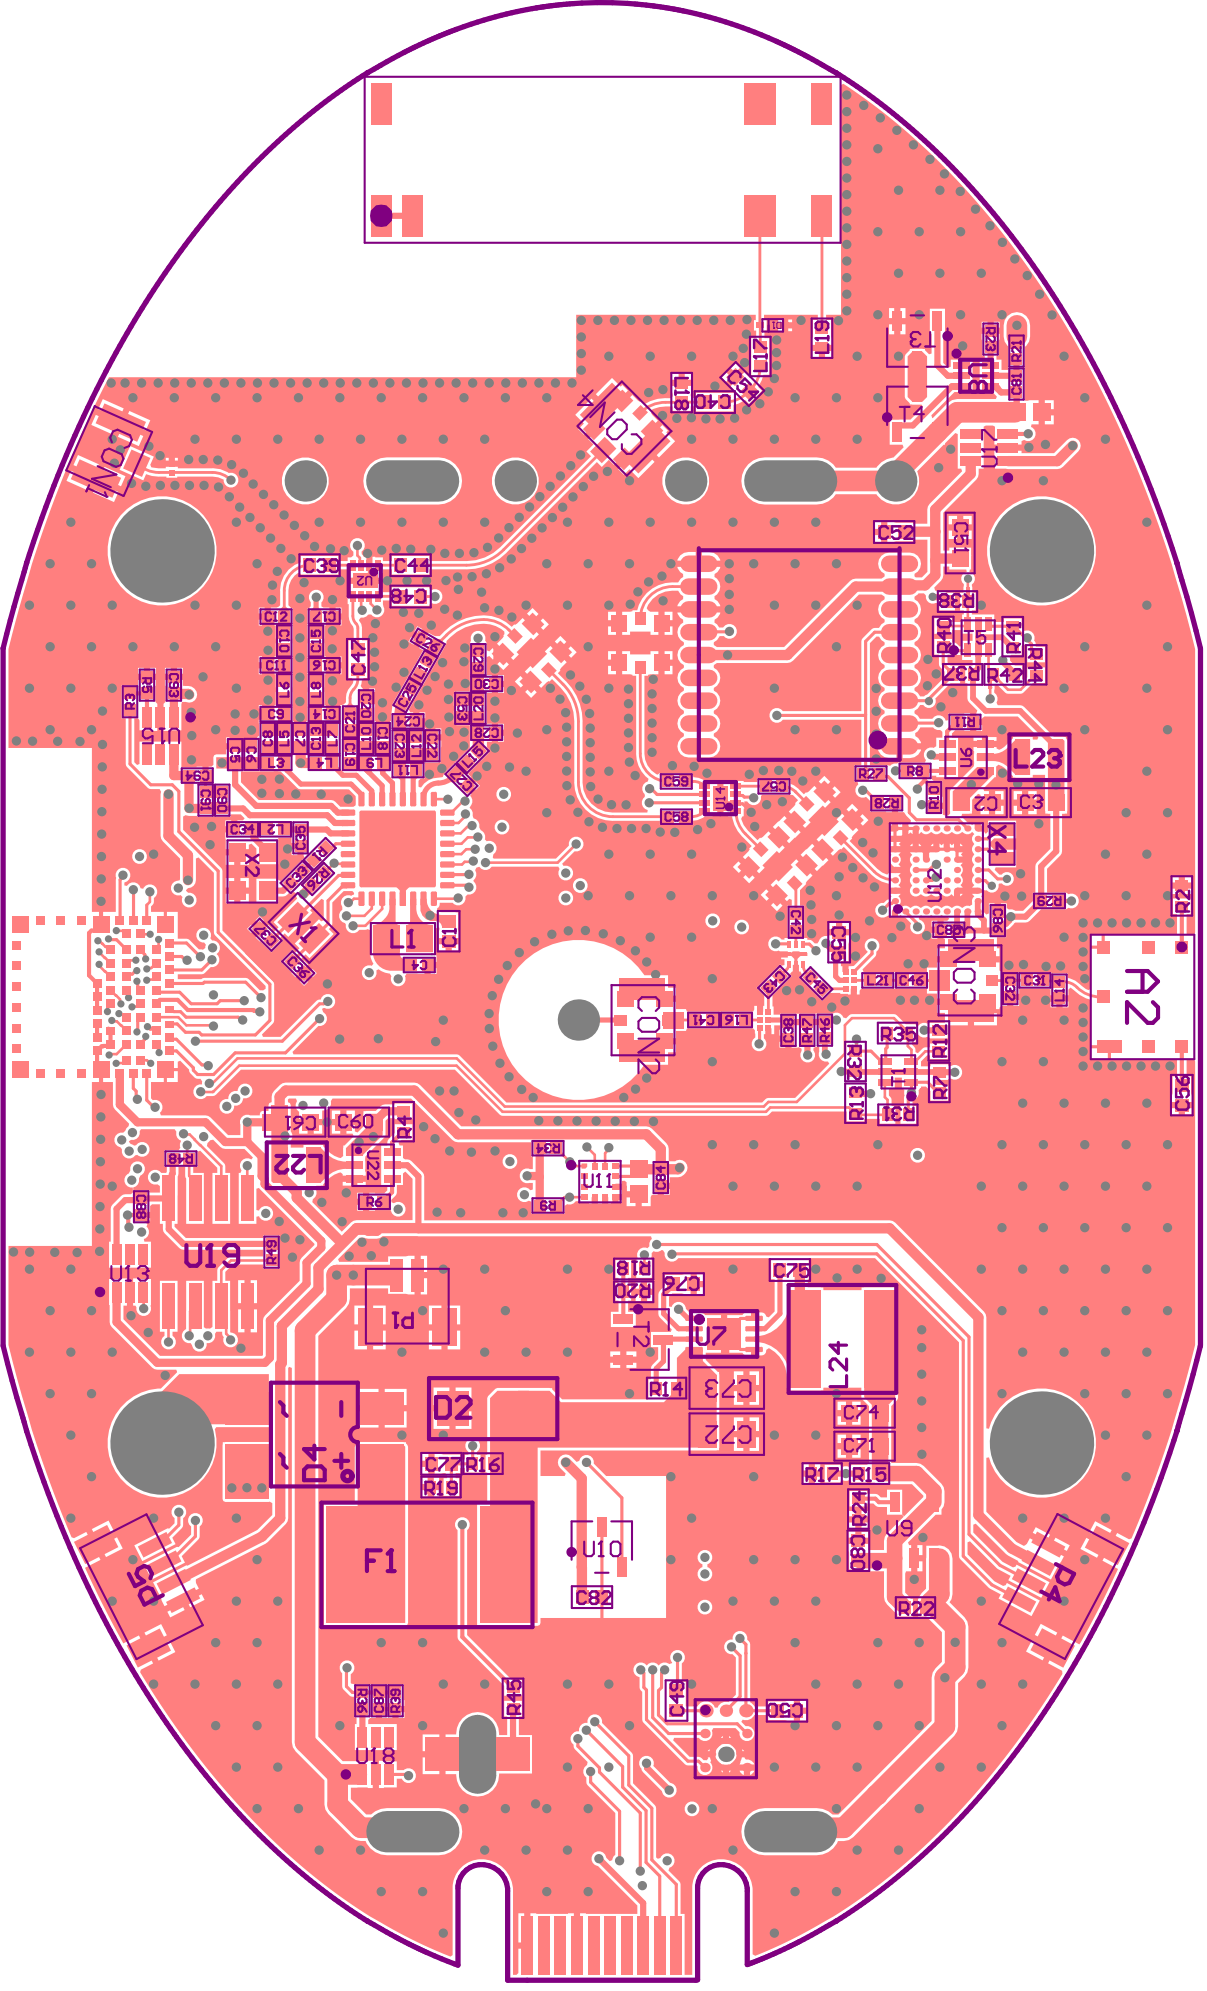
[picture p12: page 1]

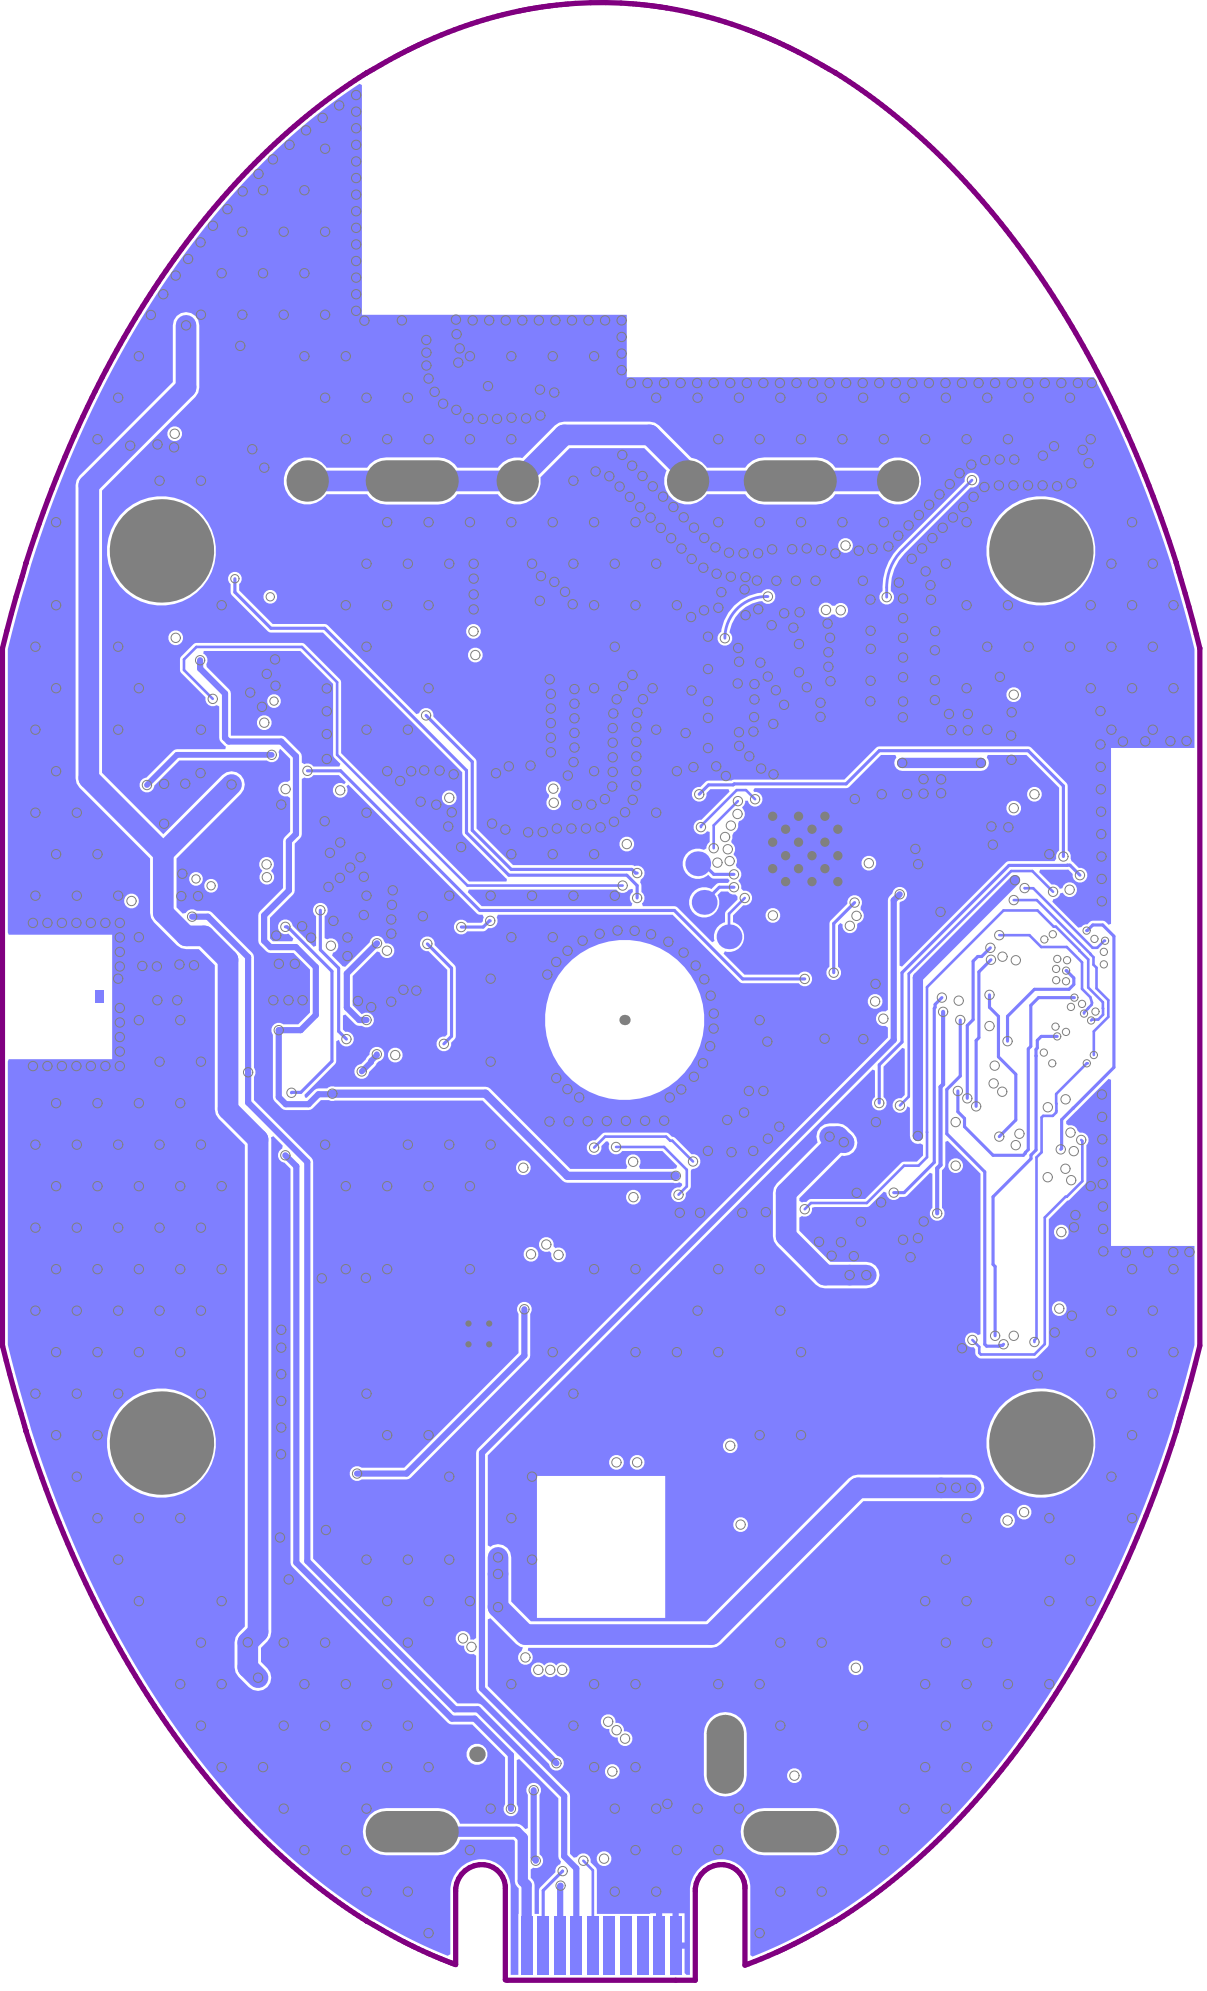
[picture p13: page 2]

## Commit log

2021-04-13 First version V0.1
    [RangerEdge_V0.1.DRL, RangerEdge_V0.1.GBL, RangerEdge_V0.1.GBO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]
2021-04-13 Gerber files update
    [RangerEdge_V0.1.GBL, RangerEdge_V0.1.GBO, RangerEdge_V0.1.GBP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]
